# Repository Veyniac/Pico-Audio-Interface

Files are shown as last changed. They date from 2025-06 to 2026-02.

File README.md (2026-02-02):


# Pico-Audio-Interface

## Description
This project is a cheap, bare-bones 2-channel USB audio interface based off of a Pi Pico board.

## Features
- 12-bit resolution
- 44.1 kHz sample rate
- 4x oversampling to reduce USB noise
- -14dB to 1.6dB gain control
- Component cost <$10
- Plug and play USB Audio Class 2.0 device
- Smaller than a credit card
- Mono or Stereo mode configurable via solder jumpers

## Disclaimers
This is not an audiophile-friendly device. Depending on what you plug it into, there may be significant USB noise.
I have done everything I can to reduce that noise, and the audio quality is great when tested with my setup, but 
be aware that your mileage may vary. My goal for this project was to make something that worked, not to try to
compete with commercial audio interfaces.

I am also not responsible if this somehow fries your USB port. Always be careful when connecting a USB cable to an
externally powered device.

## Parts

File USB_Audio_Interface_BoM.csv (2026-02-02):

Reference | Part | Value | Size/Package | Qty | Notes | Digikey
A1 | Raspberry Pi Pico | ~ | ~ | 1 | Can also get version with soldered headers | https://www.digikey.com/en/products/detail/raspberry-pi/SC0915/13624793
C1,C2,C3,C6,C9,C10,C12,C14 | Surface Mount Capacitor | 0.1uF 100V | 0805 | 8 |  | https://www.digikey.com/en/products/detail/samsung-electro-mechanics/CL21B104KCFNNNE/5961324
C4,C5,C7,C8 | Surface Mount Capacitor | 330pF 50V | 0805 | 4 |  | https://www.digikey.com/en/products/detail/kemet/C0805C331K5RACTU/411139
C11,C13 | Surface Mount Capacitor | 10uF 25V | 0805 | 2 |  | https://www.digikey.com/en/products/detail/cal-chip-electronics-inc/GMC21X7R106K25NT/22640097
J1 | Stereo Audio Jack | 3523 | ~ | 1 |  | https://www.digikey.com/en/products/detail/same-sky-formerly-cui-devices/SJ1-3523N/738689
R1,R2,R5,R6 | Surface Mount Resistor | 100k | 0805 | 4 |  | https://www.digikey.com/en/products/detail/yageo/RC0805FR-07100KL/727544
R3,R4 | Surface Mount Resistor | 20k | 0805 | 2 |  | https://www.digikey.com/en/products/detail/yageo/RC0805FR-0720KL/727720
R7,R8,R9,R10,R11,R12 | Surface Mount Resistor | 10k | 0805 | 6 |  | https://www.digikey.com/en/products/detail/yageo/RC0805FR-0710KL/727535
RV1,RV2 | Potentiometer | 100k | PTV09 | 2 | Most vertical snap-in pots will also work | https://www.digikey.com/en/products/detail/bourns-inc/PTV09A-4015U-B104/6153484
U1 | Quad Op-amp | MCP6004 | SOIC-14 | 1 |  | https://www.digikey.com/en/products/detail/microchip-technology/MCP6004T-I-SL/523092

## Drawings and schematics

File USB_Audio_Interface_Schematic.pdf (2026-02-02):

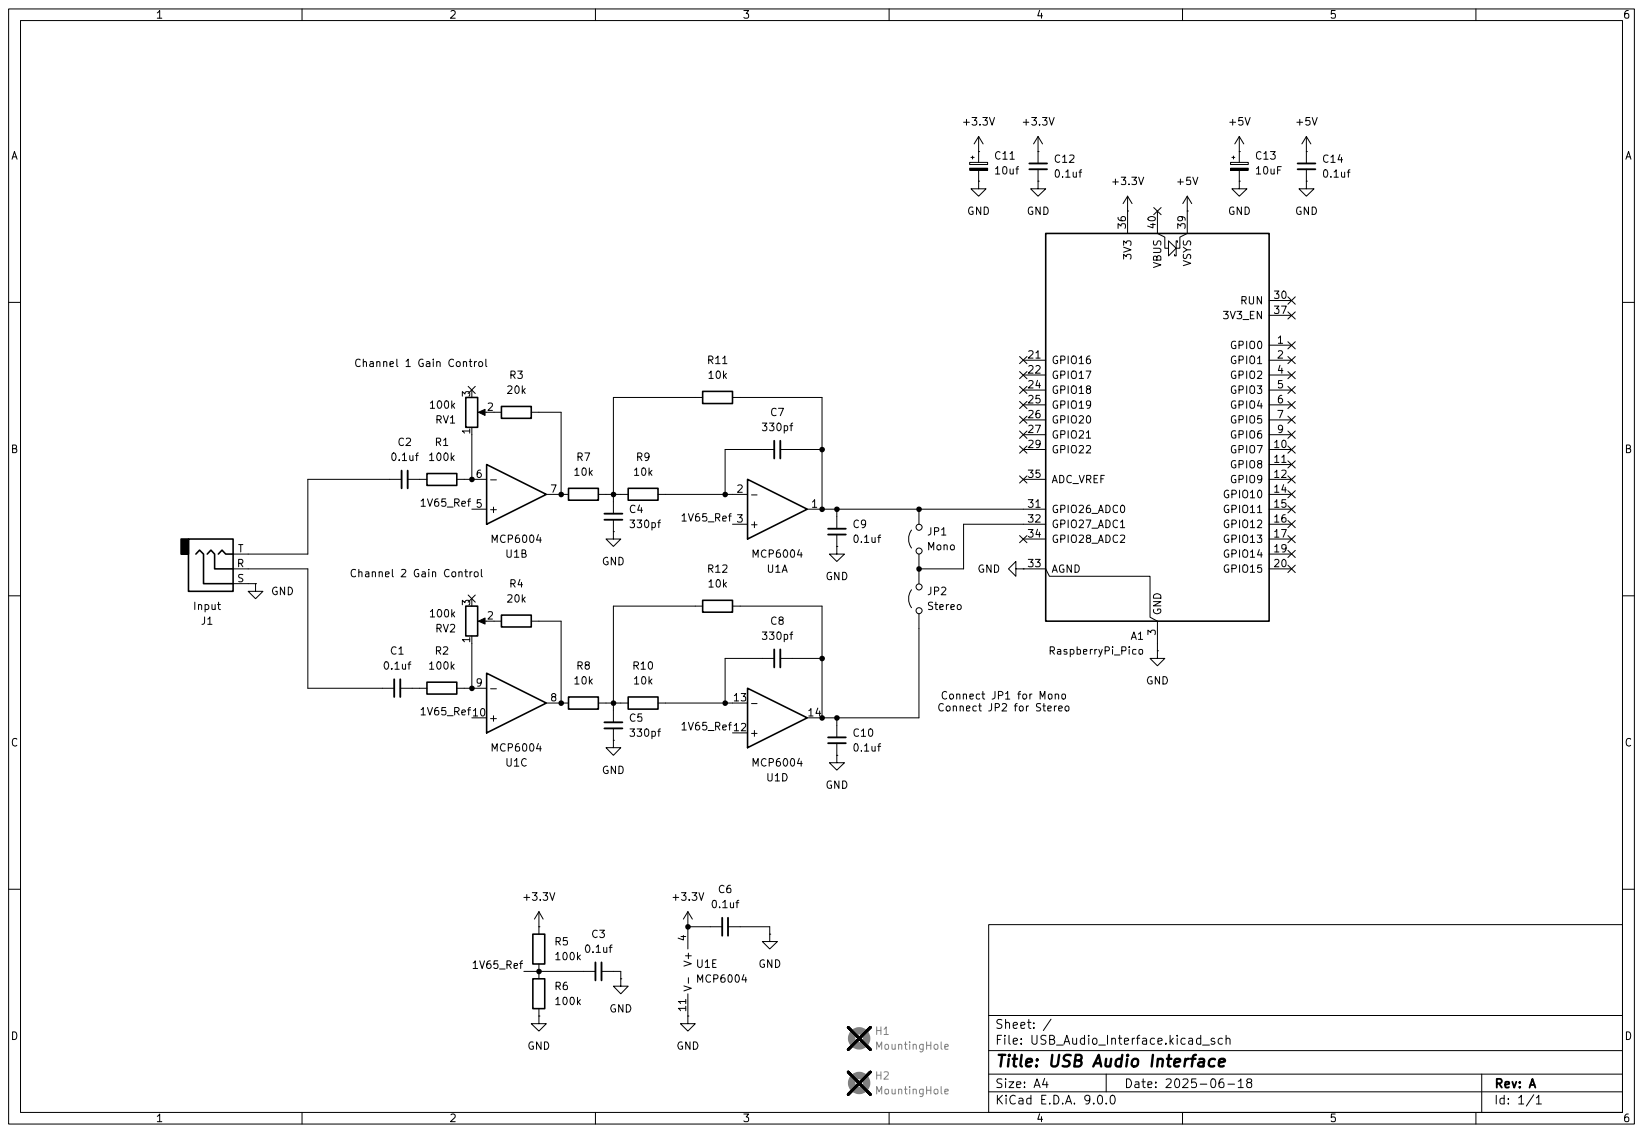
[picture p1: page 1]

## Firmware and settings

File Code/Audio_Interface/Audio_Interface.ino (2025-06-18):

#include "PluggableUSBAudio.h"
#include "hardware/dma.h"
#include "hardware/adc.h"
#include "hardware/gpio.h"
#include "hardware/irq.h"

#define NUM_CHANNELS 2
#define SAMPLE_FREQ 44100 //Audacity throws a fit if I use anything else
#define BUFFER_DEPTH 1024 //16-bit word depth, not byte. This does not control the sample depth
#define OVERSAMPLING_RATIO 4 //how many ADC samples per audio sample. This is max achievable on Pi Pico

volatile bool buffer1Ready = false;
volatile bool buffer2Ready = false;
volatile int16_t buffer1[BUFFER_DEPTH*OVERSAMPLING_RATIO] __attribute__((aligned(BUFFER_DEPTH*2*OVERSAMPLING_RATIO)));
volatile int16_t buffer2[BUFFER_DEPTH*OVERSAMPLING_RATIO] __attribute__((aligned(BUFFER_DEPTH*2*OVERSAMPLING_RATIO)));
int16_t outputBuffer[BUFFER_DEPTH];
uint8_t *outputBufferPtr = (uint8_t *)outputBuffer;
int16_t high;
int16_t low;
uint highLocation;
uint lowLocation;

USBAudio audio(true, SAMPLE_FREQ, NUM_CHANNELS, SAMPLE_FREQ, NUM_CHANNELS);

dma_channel_config c1;
dma_channel_config c2;

uint dma_channel_1;
uint dma_channel_2;

void dma_handler_irq0(){
  buffer1Ready = true;
  dma_hw->ints0 = 1u << dma_channel_1; //reset interrupt status
}

void dma_handler_irq1(){
  buffer2Ready = true;
  dma_hw->ints1 = 1u << dma_channel_2; //reset interrupt status
}

void setup(){
  while(!audio.configured()){}
  audio.write_wait_ready();

  _gpio_init(23);
  adc_init();
  gpio_set_dir(23,true);
  gpio_put(23,true);
  adc_gpio_init(26); //left channel
  adc_gpio_init(27); //right channel
  //adc_gpio_init(28); //channel 3?
  adc_select_input(0); //start with left channel
  adc_set_round_robin(0b1<<0 | 0b1<<1);
  adc_set_clkdiv((48000000/(SAMPLE_FREQ*2*OVERSAMPLING_RATIO))-1); //sampling frequency calculation
  adc_fifo_setup(true,true,1,false,false);

  dma_channel_1 = dma_claim_unused_channel(true);
  dma_channel_2 = dma_claim_unused_channel(true);

  c1 = dma_channel_get_default_config(dma_channel_1);
  channel_config_set_read_increment(&c1, false);
  channel_config_set_write_increment(&c1, true);
  channel_config_set_ring(&c1,true,log2(BUFFER_DEPTH*2*OVERSAMPLING_RATIO));
  channel_config_set_dreq(&c1, DREQ_ADC);
  channel_config_set_transfer_data_size(&c1, DMA_SIZE_16);
  channel_config_set_enable(&c1, true);
  channel_config_set_chain_to(&c1,dma_channel_2);

  c2 = dma_channel_get_default_config(dma_channel_2);
  channel_config_set_read_increment(&c2, false);
  channel_config_set_write_increment(&c2, true);
  channel_config_set_ring(&c2,true,log2(BUFFER_DEPTH*2*OVERSAMPLING_RATIO));
  channel_config_set_dreq(&c2, DREQ_ADC);
  channel_config_set_transfer_data_size(&c2, DMA_SIZE_16);
  channel_config_set_enable(&c2, true);
  channel_config_set_chain_to(&c2,dma_channel_1);

  dma_channel_configure(dma_channel_1,&c1,&buffer1,&adc_hw->fifo,BUFFER_DEPTH*OVERSAMPLING_RATIO,false);
  dma_channel_configure(dma_channel_2,&c2,&buffer2,&adc_hw->fifo,BUFFER_DEPTH*OVERSAMPLING_RATIO,false);

  dma_channel_set_irq0_enabled(dma_channel_1,true);
  dma_channel_set_irq1_enabled(dma_channel_2,true);
  irq_set_exclusive_handler(DMA_IRQ_0,dma_handler_irq0);
  irq_set_exclusive_handler(DMA_IRQ_1,dma_handler_irq1);

  irq_set_enabled(DMA_IRQ_0,true);
  irq_set_enabled(DMA_IRQ_1,true);
  dma_channel_start(dma_channel_1);
  adc_run(true);
}

void loop(){
  if(buffer1Ready){
    for(uint i=0;i<BUFFER_DEPTH;i+=2){
      outputBuffer[i] = 0;
      outputBuffer[i+1] = 0;

      //the following code takes the four sample values for each channel, throws out the highest and lowest, averages the remaining two, and converts to signed 16-bit PCM
      high = -1;
      low = 4096;

      for(int j=i*OVERSAMPLING_RATIO;j<(i+2)*OVERSAMPLING_RATIO;j+=2){ //find high and low values
        if(buffer1[j]>high){
          high = buffer1[j];
          highLocation = j;
        }
        if(buffer1[j]<low){
          low = buffer1[j];
          lowLocation = j;
        }
      }
      
      if(highLocation==lowLocation) outputBuffer[i] = buffer1[lowLocation]*2;
      else{
        for(uint k=i*OVERSAMPLING_RATIO;k<(i+2)*OVERSAMPLING_RATIO;k+=2){ 
        if(k==highLocation || k==lowLocation) continue; //throw out highest and lowest values
        else outputBuffer[i] += buffer1[k]; //add median values
        }
      }
      
      outputBuffer[i] = (outputBuffer[i]<<(5-(int)log2(OVERSAMPLING_RATIO)))^0x8000; //convert to signed PCM data format

      high = -1;
      low = 4096;

      for(int j=i*OVERSAMPLING_RATIO+1;j<(i+2)*OVERSAMPLING_RATIO+1;j+=2){ //find high and low values
        if(buffer1[j]>high){
          high = buffer1[j];
          highLocation = j;
        }
        if(buffer1[j]<low){
          low = buffer1[j];
          lowLocation = j;
        }
      }

      if(highLocation==lowLocation) outputBuffer[i+1] = buffer1[lowLocation]*2;
      else{
        for(uint k=i*OVERSAMPLING_RATIO+1;k<(i+2)*OVERSAMPLING_RATIO+1;k+=2){
        if(k==highLocation || k==lowLocation) continue; //throw out highest and lowest values
        else outputBuffer[i+1] += buffer1[k]; //add median values
        }
      }
      
      outputBuffer[i+1] = (outputBuffer[i+1]<<(5-(int)log2(OVERSAMPLING_RATIO)))^0x8000; //fast convert to signed PCM data format
    }

    if(audio.write(outputBufferPtr, BUFFER_DEPTH*2)){ //send the audio buffer data over USB
      buffer1Ready = false;
    } 
  }

  if(buffer2Ready){
    for(uint i=0;i<BUFFER_DEPTH;i+=2){
      outputBuffer[i] = 0;
      outputBuffer[i+1] = 0;

      //the following code takes the four sample values for each channel, throws out the highest and lowest, averages the remaining two, and converts to signed 16-bit PCM
      high = -1;
      low = 4096;

      for(int j=i*OVERSAMPLING_RATIO;j<(i+2)*OVERSAMPLING_RATIO;j+=2){ //find high and low values
        if(buffer2[j]>high){
          high = buffer2[j];
          highLocation = j;
        }
        if(buffer2[j]<low){
          low = buffer2[j];
          lowLocation = j;
        }
      }

      if(highLocation==lowLocation) outputBuffer[i] = buffer2[lowLocation]*2;
      else{
        for(uint k=i*OVERSAMPLING_RATIO;k<(i+2)*OVERSAMPLING_RATIO;k+=2){ 
        if(k==highLocation || k==lowLocation) continue; //throw out highest and lowest values
        else outputBuffer[i] += buffer2[k]; //add median values
        }
      }

      outputBuffer[i] = (outputBuffer[i]<<(5-(int)log2(OVERSAMPLING_RATIO)))^0x8000; //convert to signed PCM data format

      high = -1;
      low = 4096;

      for(int j=i*OVERSAMPLING_RATIO+1;j<(i+2)*OVERSAMPLING_RATIO+1;j+=2){ //find high and low values
        if(buffer2[j]>high){
          high = buffer2[j];
          highLocation = j;
        }
        if(buffer2[j]<low){
          low = buffer2[j];
          lowLocation = j;
        }
      }

      if(highLocation==lowLocation) outputBuffer[i+1] = buffer2[lowLocation]*2;
      else{
        for(uint k=i*OVERSAMPLING_RATIO+1;k<(i+2)*OVERSAMPLING_RATIO+1;k+=2){
        if(k==highLocation || k==lowLocation) continue; //throw out highest and lowest values
        else outputBuffer[i+1] += buffer2[k]; //add median values
        }
      }
      outputBuffer[i+1] = (outputBuffer[i+1]<<(5-(int)log2(OVERSAMPLING_RATIO)))^0x8000; //convert to signed PCM data format
    }

    if(audio.write(outputBufferPtr, BUFFER_DEPTH*2)){ //send the audio buffer data over USB
      buffer2Ready = false;
    } 
  }
}

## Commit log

2026-02-02 Delete USB_Audio_Interface_Schematic.pdf
    Deleted old schematic
2026-02-02 Added new schematic
